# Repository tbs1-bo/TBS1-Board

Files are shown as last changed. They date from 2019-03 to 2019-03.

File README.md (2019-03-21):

# TBS1-Board

Das "TBS1-Board" ist ein Übungsboard zur Programmierung von Mikrocontrollern. Es wurde 2017 im Rahmen eines Projektes der Fachschule für Technik an der Technischen Beruflichen Schule 1 in Bochum (TBS1) entwickelt. Das Übungsboard kommt bei der Technikerausbildung zum Einsatz.

## TBS1-Board 2017

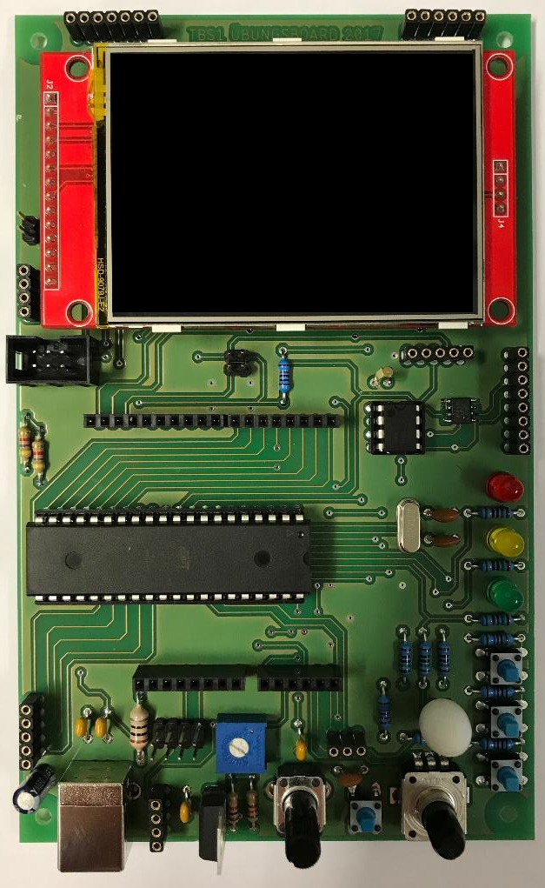
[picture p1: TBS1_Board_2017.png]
TBS1-Board 2017


- [Projektdokumentation (Auszug)](Projektdokumentation_2017_Auszug.pdf)
- [Schaltung und Platinenlayout](Schaltung_und_Platinenlayout)

## Weiterentwicklung

Infos folgen ...

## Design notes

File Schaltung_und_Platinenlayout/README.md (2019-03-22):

# TBS1-Board / Schaltung und Platinenlayout (Stand: 2017)

- [Stückliste](Stueckliste_2017.pdf)

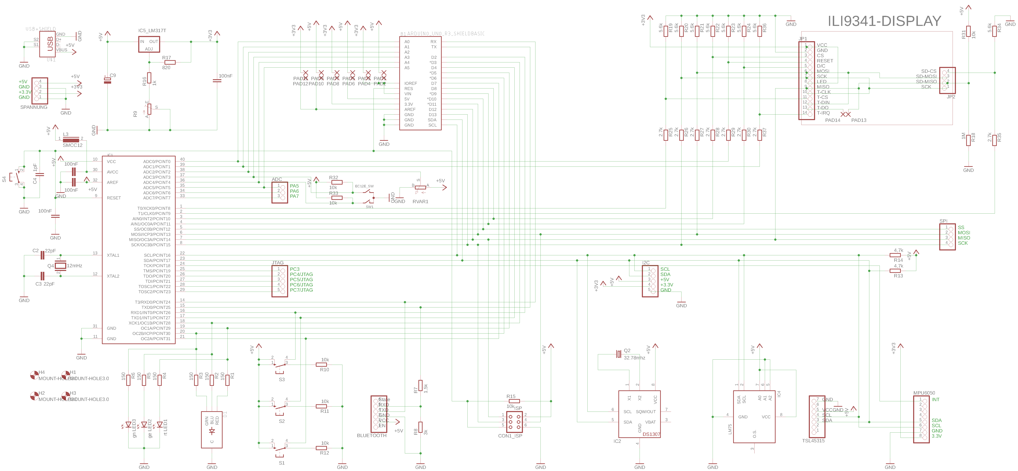
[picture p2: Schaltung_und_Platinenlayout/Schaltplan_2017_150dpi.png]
TBS1-Board Schaltplan

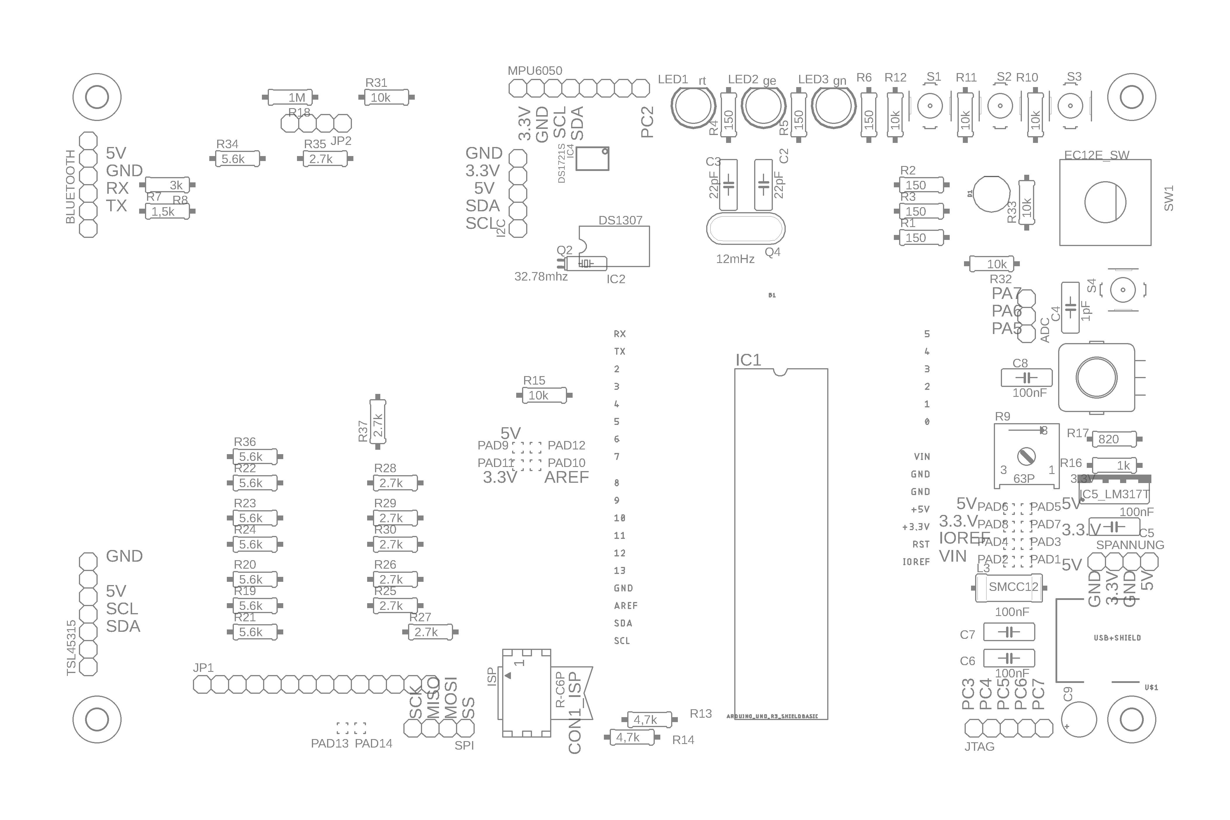
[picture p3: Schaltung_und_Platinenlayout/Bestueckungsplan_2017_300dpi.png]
TBS1-Board Bestückungsplan


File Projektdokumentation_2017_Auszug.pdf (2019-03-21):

Zusammenfassung | [9]

## 1 Zusammenfassung

Die Projektgruppe hat sich für das schulinterne Projekt „Re-Design des TBS1-Boards“ entschieden. Dieses bietet der Projektgruppe die Möglichkeit, sich in ein für alle Gruppenmitglieder neues Themengebiet einzuarbeiten. Die Motivation der Projektgruppe ist die individuelle Weiterentwicklung im Bereich der Mikrocontrollertechnik und das Lösen neuer Herausforderungen. Technische Herausforderung der Projektgruppe war die Einarbeitung in die Programmiersprache C und der Umgang mit dem AVR Studio. Ziel dieses Projektes ist die Planung und Entwicklung eines neuen Mikrocontroller-Übungsboards, das in Form einer Platine übergeben wird. Studierende des Fachbereiches „Elektrotechnik“ werden das Übungsboard in Lernfeld 9 an der TBS1 nutzen, um Kenntnisse der Mikrocontrollertechnik zu erlangen und zu vertiefen.

Basierend auf einem Übungsboard, das im Jahre 2011 gefertigt wurden, wurde das TBS1-Übungsboard nach neuen Anforderungen des Unterrichtskonzepts entwickelt. Diese enthalten die Ansteuerung von einer RGB-LED, eine Verwendung eines TFT Multi-Color-Displays, die Kommunikation über Bluetooth-Module und I²C-Busteilnehmern. Zu Beginn des Projekts wurde der Ist-Zustand des alten Übungsboards genau analysiert. So konnte geprüft werden, welche Komponenten auf das TBS1-Board übernommen werden konnten.

Aufgrund der komplexen und anspruchsvollen Änderungen, die vorgenommen mussten, wurde das Gesamtprojekt innerhalb der Gruppe in Teilprojekte aufgeschlüsselt. Nachdem
Recherche-, | Programmierungs- | und | Entwicklungsphase | der | Einzelprojekte
abgeschlossen waren, konnten die Projekte für die Realisierung des Übungsboards zusammengefügt werden. Dazu wurden Steckboardversuche durchgeführt, um das Zusammenspiel aller Komponenten des TBS1-Übungsboards zu testen und mögliche Fehler ausfindig zu machen. Nachdem keine Fehlerquellen mehr in der Hard- und Software ausfindig gemacht werden konnten, wurde mit der Herstellung des Platinenlayouts begonnen. Die maschinell hergestellte Prototypplatine konnte den weitreichenden Anwendungstests standhalten und so durch die TBS1 in Serienfertigung gegeben werden. Des Weiteren wurde eine Gesamtsimulation mit dem Programm „Proteus 8 Professional“ entwickelt, sodass die Funktion des Übungsboards auch an einem Computer voll simulierfähig genutzt werden kann. Am Ende des Projekts konnte dem Auftraggeber ein voll funktionsfähiges Mikrocontroller-Übungsboard mit Simulationsprogramm und vollständiger Dokumentation übergeben werden.

Abstract | [10]

## 2 Abstract

The project team decided to deal with the school internal topic "Re-Design of the TBS1-Board". Thus, all the members of the project team are given the opportunity to work on new thematics. The motivation of the project team consists of the individual development in the field of microcontroller technology as well as facing new challenges. Technical challenges the team had to face were the initial training concerning the programming language C and handling the AVR-Studio. The aim of this project is the design and the development of a new microcontroller practice board which will be handed over in form of a printed circuit board. The practice board will be used by students of the department of electrical engineering in the course of learning field 9 at the TBS1 in order to gain and to deepen their knowledge in microcontroller technology

Based on a practice board which was manufactured in 2011 the new TBS1 practice board was developed according to the new tasks of the tuitional concept. These include the activation of a RGB-LED, the usage of a TFT Multi-Color-Display, the communication via Bluetooth modules and I²C-Bus participants. At the beginning of the project the actual state of the old practice board was analysed in detail. Thus, it could be examined which components could be taken over on the new TBS1 board.

Due to complex and demanding modifications that had to be made the overall project was divided into several sub-projects among the participants. After finishing the different stages of research, programming and development of the single projects, these could be put together for the realisation of the practice board. For this purpose breadboard experiments were performed in order to test the interaction of all the components of the TBS1 practice board and to detect possible faults. As no more faults could be detected in hardware and software the production of the printed circuit board layout started. The machine-made prototype circuit board could stand the close examination and thus the batch fabrication could start. Moreover, an over-all simulation was developed with the programme "Proteus 8 Professional". Consequently the function of the practice board can also be simulated on a computer. At the end of the project the client received a fully operative microcontroller practice board including a simulation programme and a complete documentation.

Einleitung | [11]

## 3 Einleitung

Die Technische Berufliche Schule 1 in Bochum nutzt in Lernfeld 9 seit 2011 ein Übungsboard. Es ermöglicht Studierenden innerhalb ihrer Weiterbildung zum „Staatlich Geprüften Techniker in der Fachrichtung Elektrotechnik“, die Kenntnisse und Fertigkeiten in der Mikrokontrollertechnik praktisch zu erlernen und zu vertiefen. Da es sich um eine sehr komplexe und wichtige Fachkompetenz handelt, setzt der Rahmenplan der Landesregierung NRW im Lernfeld 9 120 bis 280 Unterrichtsstunden an. Das TBS1-Board wird dazu von jedem Studierenden selbst gefertigt. Durch die beiliegende Materialliste können alle benötigten Komponenten bestellt und die TBS1-Board-Platine durch die Studierenden bestückt und gelötet werden.

Das bis dato genutzte TBS1-Übungsboard erwies sich als nützliche Komponente, die theoretisch erlernten Kenntnisse der Mikrocontrollertechnik sofort an praktischer Hardware anwenden zu können. Grund für die Überarbeitung des TBS1-Boards war es, das Übungsboard wieder auf den aktuellsten Stand der Technik zu bringen und eine Serienfertigung für die nächsten Schuljahre zu ermöglichen.

Im Folgenden weitere Gründe für das Re-Design des TBS1-Boards:

- Bevorstehende Großbestellung neuer Platinen
- TFT Multicolor-Display zum gleichen Preis des bisherigen Zwei-Zeilen-Monochrom-Grafikdisplay erhältlich. Grafiken und Diagramme können so dargestellt werden.
- Neue Möglichkeiten ausschöpfen (Einbindung von Bluetooth-Modulen, Ansteuerung einer RGB-LED, weiterführende Nutzung von I²C-Sensorik)
- Kompatibilität mit Arduino-Komponenten ermöglichen

Projektteam | [12]

## 4 Projektteam

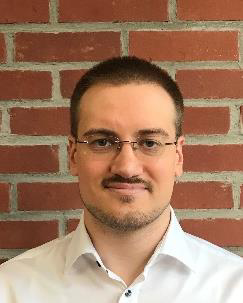
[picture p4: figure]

Name: | Martin Janocha
Geboren am: | 11.10.1989
Ausbildung: | Elektroniker für Energie- und Gebäudetechnik
Letzter Arbeitgeber: Walter Elektro Anlagentechnik GmbH
Aufgabenbereich: | Schaltschrankbau

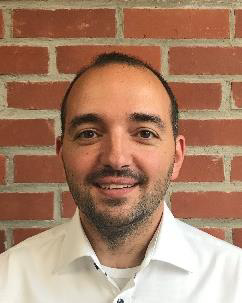
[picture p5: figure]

Name: | Christoph Nabring
Geboren am: | 19.04.1980
Ausbildung: | Elektroniker für Energie- und Gebäudetechnik
Letzter Arbeitgeber: United Cinemas International Multiplex GmbH
Aufgabenbereich: | Facility Management (GLT etc.)

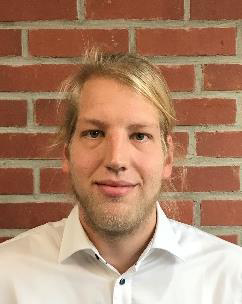
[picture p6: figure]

Name: | Dustin Rosemann
Geboren am: | 16.02.1992
Ausbildung: | Elektroniker für Betriebstechnik
Letzter Arbeitgeber: Vossloh Fastening Systems AG
Aufgabenbereich: | Internationales Projektmanagement

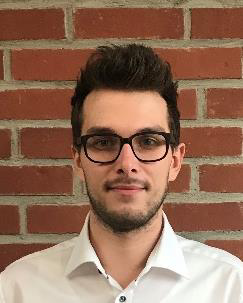
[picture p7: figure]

Name: | Nathanael Runge
Geboren am: | 19.06.1992
Ausbildung: | Mechatroniker
Letzter Arbeitgeber: Alanod GmbH Aufgabenbereich: SPS-Automatisierung

TBS1-Boards im Vergleich | [13]

## 5 TBS1-Boards im Vergleich

Um einen direkten Vergleich der TBS1-Boards zu erlangen, sind die TBS1-Boards in den folgenden zwei Abbildungen gegenübergestellt.

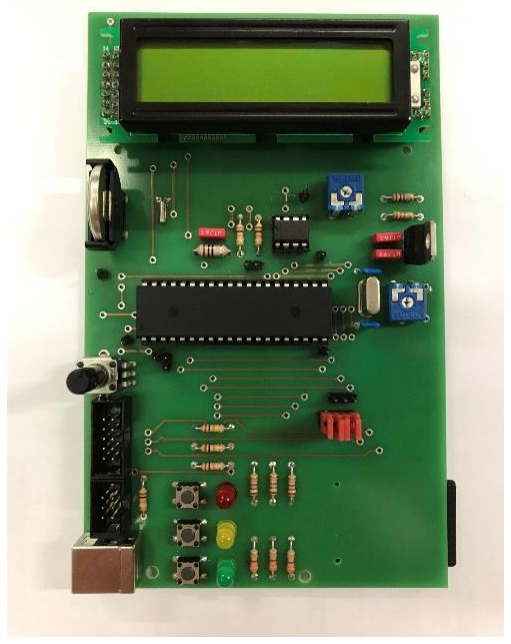
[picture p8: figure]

Die Auflistung der Hauptkomponenten des TBS1-Boards von 2011:

- Mikrocontroller ATmega 32
- Zwei-Zeilen-Monochrom-Display
- SD-Karten-Schnittstelle (ohne konstante Funktion)
- Temperaturbaustein DS-1621
- RealTimeClock DS-1338
- Drehpotentiometer
- LED-Ampel
- Drei Kurzhubtaster

Abb. 1: TBS1-Board 2011

TBS1-Boards im Vergleich | [14]

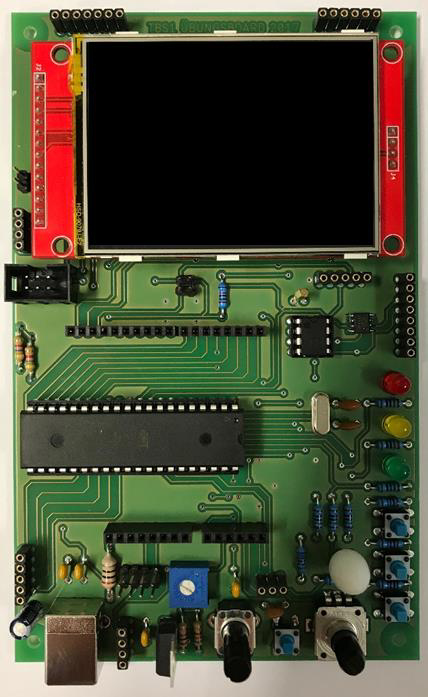
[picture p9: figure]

Abb. 2: TBS1-Board 2017
Die Auflistung der Hauptkomponenten des TBS1-Board von 2017:
- Mikrocontroller ATmega 1284P
- TFT Multicolor-Grafikdisplay
- SD-Karten-Schnittstelle
- Temperatursensor LM75A
- Drehimpulsgeber
- Drehpotentiometer
- RealTimeClock DS-1338
- LED-Ampel
- Drei Kurzhubtaster
- RGB-LED
- Resetbutton
- Steckleiste für Arduino-Shields
- Steckleiste für Lichtsensor TSL45315
- Steckleiste für Gyrosensor MPU-6050
- Steckleiste für Bluetooth-Module (IOS und Android)
- Breakout für SPI
- Breakout für I²C

TBS1-Boards im Vergleich | [15]
- Breakout für JTAG
- Breakout für ADC-Eingänge
- Breakout für Interrupteingänge
- Breakout der Spannungsversorgung (3,3V; 5V; Masse)

Bei der Entwicklung des TBS1-Boards wurde auf eine bedienerfreundliche und kompakte Bauform geachtet. An den Steckleisten am Rand des TBS1-Boards können Sensoren bei Bedarf hinzugefügt oder entfernt werden. Um das Übungsboard durch weitere, nicht eingeplante Komponenten oder Sensoren zu erweitern, können die verschiedenen Breakouts genutzt werden. Es ermöglicht u. A. das Einbinden weiterer Sensoren in den I²C-Bus, die Erweiterung von SPI-Komponenten oder die Nutzung von nicht belegten Hardwarepins am ATmega1284P. Für weitergehende Programmierungsmöglichkeiten kann natürlich auch das Arduino-Shield-Breakout genutzt werden.

Der Mikrocontroller ATmega1284P | [16]

## 6 Der Mikrocontroller ATmega1284P

Der Mikrocontroller, auch Halbleiterchip bzw. „Ein-Chip-Mikrorechner“, ist ein Rechensystem, welches eine ähnliche Funktionsweise wie ein Computer hat. Im Gegensatz zu einem PC sind die Eigenschaften, der Programmspeicher (Flash), der Datenspeicher (RAM), die Verarbeitungseinheit (CPU), die digitalen und analogen Ein-/Ausgabe-Ports, Kommunikationsbausteine (COM, UART, etc.), Zeitgeber usw., alle auf dem Mikrocontroller vereint. Durch diese Minimalisierung und die individuelle Anwendungsanpassung können die Produktionskosten drastisch gesenkt werden. Dementsprechend gibt es viele unterschiedliche Varianten, welche sich in der Bauform und dem Funktionsumfang unterscheiden. Der Mikrocontroller übernimmt, je nach Programmierung, bei seiner Anwendung meistens Überwachungs-, Steuer- oder Regelaufgaben. So kommen Mikrocontroller in immer mehr elektrischen Geräten des alltäglichen Lebens zum Einsatz, wie z.B. Fernsehern, Waschmaschinen, Mobiltelefonen, Steuergeräten von Kraftfahrzeugen, Uhren und Heizungsreglern. Mikrocontroller können mit verschiedenen Programmiersprachen programmiert werden. Zu den gängigsten Programmiersprachen zählen z.B. Assembler, Basic, Arduino-C, C++ oder C.

Für dieses Projekt wird der ATmega1284P ausgewählt, da er im Vergleich zum zuvor benutzten ATmega32 einen vier Mal größeren internen Flash-Speicher und EEPROM sowie einen acht Mal größeren SRAM besitzt. Dadurch können z.B. größere Libraries, wie die des Displays, gespeichert und verarbeitet werden. Beide Mikrocontroller sind hinsichtlich der Abmaße baugleich und benötigen beide einen 40-Pin-Sockel.

Der ATmega1284P gehört zur 8-Bit-Mikrocontroller-Familie des US-amerikanischen Herstellers Microchip Technology´s. Eine genauere Beschreibung der Funktionen ist dem Datenblatt zu entnehmen.

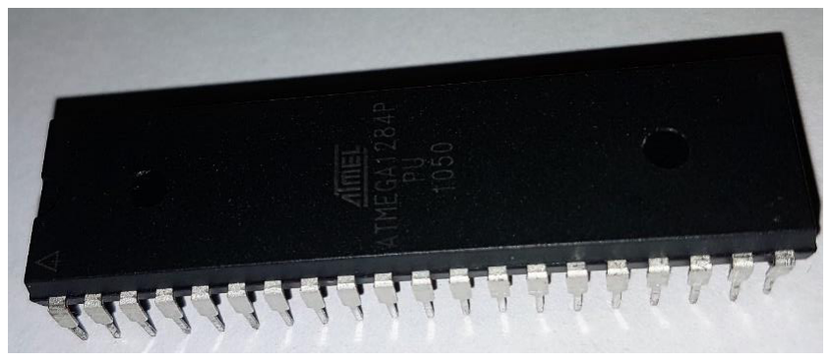
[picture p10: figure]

Abb. 3: ATmega 1284p (DIL40)

Der Mikrocontroller ATmega1284P | [17]

Im Rahmen des Projektes werden folgende Funktionen zur Umsetzung verwendet:

- SPI-Schnittstelle (Serial Peripheral Interface)
Diese Schnittstelle ist ein Bussystem, über welches mehrere Komponenten gleichzeitig kommunizieren können. Bei dem Projekt dient sie zur Kommunikation zwischen dem Display, der SD-Karte und dem ATmega1284P.
- ISP-Schnittstelle (In System Programming)
Diese Schnittstelle teilt sich die Pins der SPI-Schnittstelle und wird von Programmiergeräten benutzt, um das fertige Programm auf den Mikrocontroller zu übertragen.
- I²C-Bus (I-Quadrat-C = Interner IC Bus)
Diese Zweidraht-Schnittstelle ist ein Bussystem, über welches mehrere I²C-Bausteine mit dem Mikrocontroller kommunizieren können.

Fuse-Bits Einstellungen Mikrocontroller | [18]

## 7 Fuse-Bits Einstellungen Mikrocontroller

Fuse-Bits dienen dazu, Einstellungen des Mikrocontrollers zu ändern, die nicht im Programm verändert werden können. Unter anderem wird damit die Nutzung des internen Takts eingestellt oder die Verwendung eines externen Quarzes. Der Mikrocontroller des Boards muss so eingestellt werden, dass der externe Takt verwendet wird.

Zur Einstellung der Fuse-Bits werden folgende Register (Bytes) verwendet:
Low-, High- und Extended-Fuse.

Die Fuse-Bits des ATmega1284P vom TBS1-Bord werden wie folgt eingestellt:
Low: 0xFF | High: 0x99 | Extended: 0xFF

Dadurch ist der Mikrocontroller so eingestellt, dass der interne Takt nicht durch 8 geteilt und ein externer Quarz akzeptiert wird.

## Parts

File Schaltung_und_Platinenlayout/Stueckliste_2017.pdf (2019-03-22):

TBS1-Board 2017 Stückliste

Stückliste (Stand: 22.03.2019)

Produkt (Reichelt) | Artikelnummer | EP (Euro)Menge GP (Euro)
Atmega 1284P | ATMEGA 1284P-PU | 4,7 | 1 | 4,7
IC Sockel 40 | GS 40 | 0,13 | 1 | 0,13
Drehpot. 10k Ohm | RK09K113-LIN10K | 0,76 | 1 | 0,76
Drehimpulsgeber | STEC12E07 | 1,7 | 1 | 1,7
Kurzhubtaster | TASTER 9308 | 0,16 | 4 | 0,64
LED ROT | LED 5MM ST RT | 0,12 | 1 | 0,12
LED GELB | LED 5MM ST GE | 0,12 | 1 | 0,12
LED GRÜN | LED 5MM ST GN | 0,12 | 1 | 0,12
RGB-LED Kathode | LED LL 5-8000RGB | 0,61 | 1 | 0,61
USB Buchse | USB BW | 0,26 | 1 | 0,26
Wannenstecker 6-polig | WSL 6G | 0,16 | 1 | 0,16
RTC Sockel SO-8 | GS 8 | 0,04 | 1 | 0,04
Quarz 12 MHz | 12,0000-HC49U-S | 0,21 | 1 | 0,21
Quarz 32,768 kHz | 32,768 MS1V-12,5 | 0,39 | 1 | 0,39
Jumper | JUMPER 2,54GL SW | 0,02 | 3 | 0,06
Jumper klein | JUMPER 2,54 SW | 0,01 | 1 | 0,01
Festspannungsregler | LM 317-220 SG | 0,22 | 1 | 0,22
Trimmpotentiometer | 76-10 1,0K | 0,3 | 1 | 0,3
Drosselspule 10u | SMCC 10μ | 0,22 | 1 | 0,22
Kondensator 1pF | KERKO-500 1,0P | 0,07 | 1 | 0,07
Kondensator 22pF | KERKO-500 22P | 0,07 | 2 | 0,14
Kondensator 100nF | KERKO 100N | 0,05 | 4 | 0,2
Kondensator 4,7uF | RAD 4,7/35 | 0,02 | 1 | 0,02
Stiftleiste 2Pin | MPE 087-1-002 | 0,05 | 1 | 0,05
Stiftleiste 4Pin | MPE 087-1-004 | 0,1 | 1 | 0,1
Stiftleiste 2x2Pin | MPE 087-2-004 | 0,09 | 1 | 0,09
Stiftleiste 2x4Pin | MPE 087-2-008 | 0,19 | 1 | 0,19
Buchsenleiste 3Pin | MPE 115-1-003 | 0,27 | 1 | 0,27
Buchsenleiste 4Pin | MPE 115-1-004 | 0,21 | 3 | 0,63
Buchsenleiste 5Pin | 1X05G7 2,54 | 0,26 | 2 | 0,52
Buchsenleiste 6Pin | BL 1X06G7 2,54 | 0,31 | 1 | 0,31
Buchsenleiste 7pin | MPE 115-1-007 | 0,4 | 1 | 0,4
Buchsenleiste 8 Pin | MPE 115-1-008 | 0,43 | 1 | 0,43
Buchsenleiste 14Pin | MPE 115-1-014 | 0,77 | 1 | 0,77
Buchsenleiste 8Pin 8,5mm | MPE 094-1-008 | 0,23 | 2 | 0,46
Buchsenleiste 6Pin 8,5mm | MPE 094-1-006 | 0,21 | 1 | 0,21
Buchsenleiste 10Pin 8,5mm | MPE 094-1-010 | 0,21 | 1 | 0,21
Temperatursensor LM75A | LM75AD | Bei Reichelt nicht verfügbar | Aus China sehr günstig
Temperatursensor (alternative)LM 75 SMD | 1,6 | 1 | 1,6
Real Time Clock | DS 1307 | 2,8 | 1 | 2,8 Aus China sehr günstig
Widerstand 150 Ohm | METALL 150 | 0,082 | 6 | 0,492
Widerstand 820 Ohm | 1/4W 820 | 0,103 | 1 | 0,103
Widerstand 1k Ohm | 1/4W 1,0K | 0,103 | 1 | 0,103
Widerstand 1,5K Ohm | 1/4W 1,5K | 0,103 | 1 | 0,103
Widerstand 2,7k Ohm | 1/4W 2,7K | 0,103 | 8 | 0,824
Widerstand 3,0K Ohm | 1/4W 3,0K | 0,103 | 1 | 0,103
Widerstand 4,7K Ohm | 1/4W 4,7K | 0,103 | 2 | 0,206
Widerstand 5,6k Ohm | 1/4W 5,6K | 0,103 | 8 | 0,824
Widerstand 10K Ohm | METALL 10,0K | 0,082 | 7 | 0,574
Widerstand 1M Ohm | 1/4W 1M | 0,103 | 1 | 0,103
23,675

Sonstiges
Platinen Herstellung | 160mm x 100mm
Display | 2.8" TFT LCD Display Touch Panel SPI Serial 240*320 ILI9341 5V/3.3V STM32
| | 6,62 € (https://www.ebay.de/itm/2-8-TFT-LCD-Display-Touch-Panel-SPI-Serial-240-320-ILI9341-5V-3-3V-STM32/382397394621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)

Optional
ACHTUNG: Das Bluetooth-Modul ist nicht mit allen Smartphones kompatibel
Lichtsensor | TSL45315 | Watterott | 7,50 €
Bluetooth-Modul | HC-05 X | Amazon

https://www.ebay.de/itm/2-8-TFT-LCD-Display-Touch-Panel-SPI-Serial-240-320-ILI9341-5V-3-3V-STM32/382397394621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

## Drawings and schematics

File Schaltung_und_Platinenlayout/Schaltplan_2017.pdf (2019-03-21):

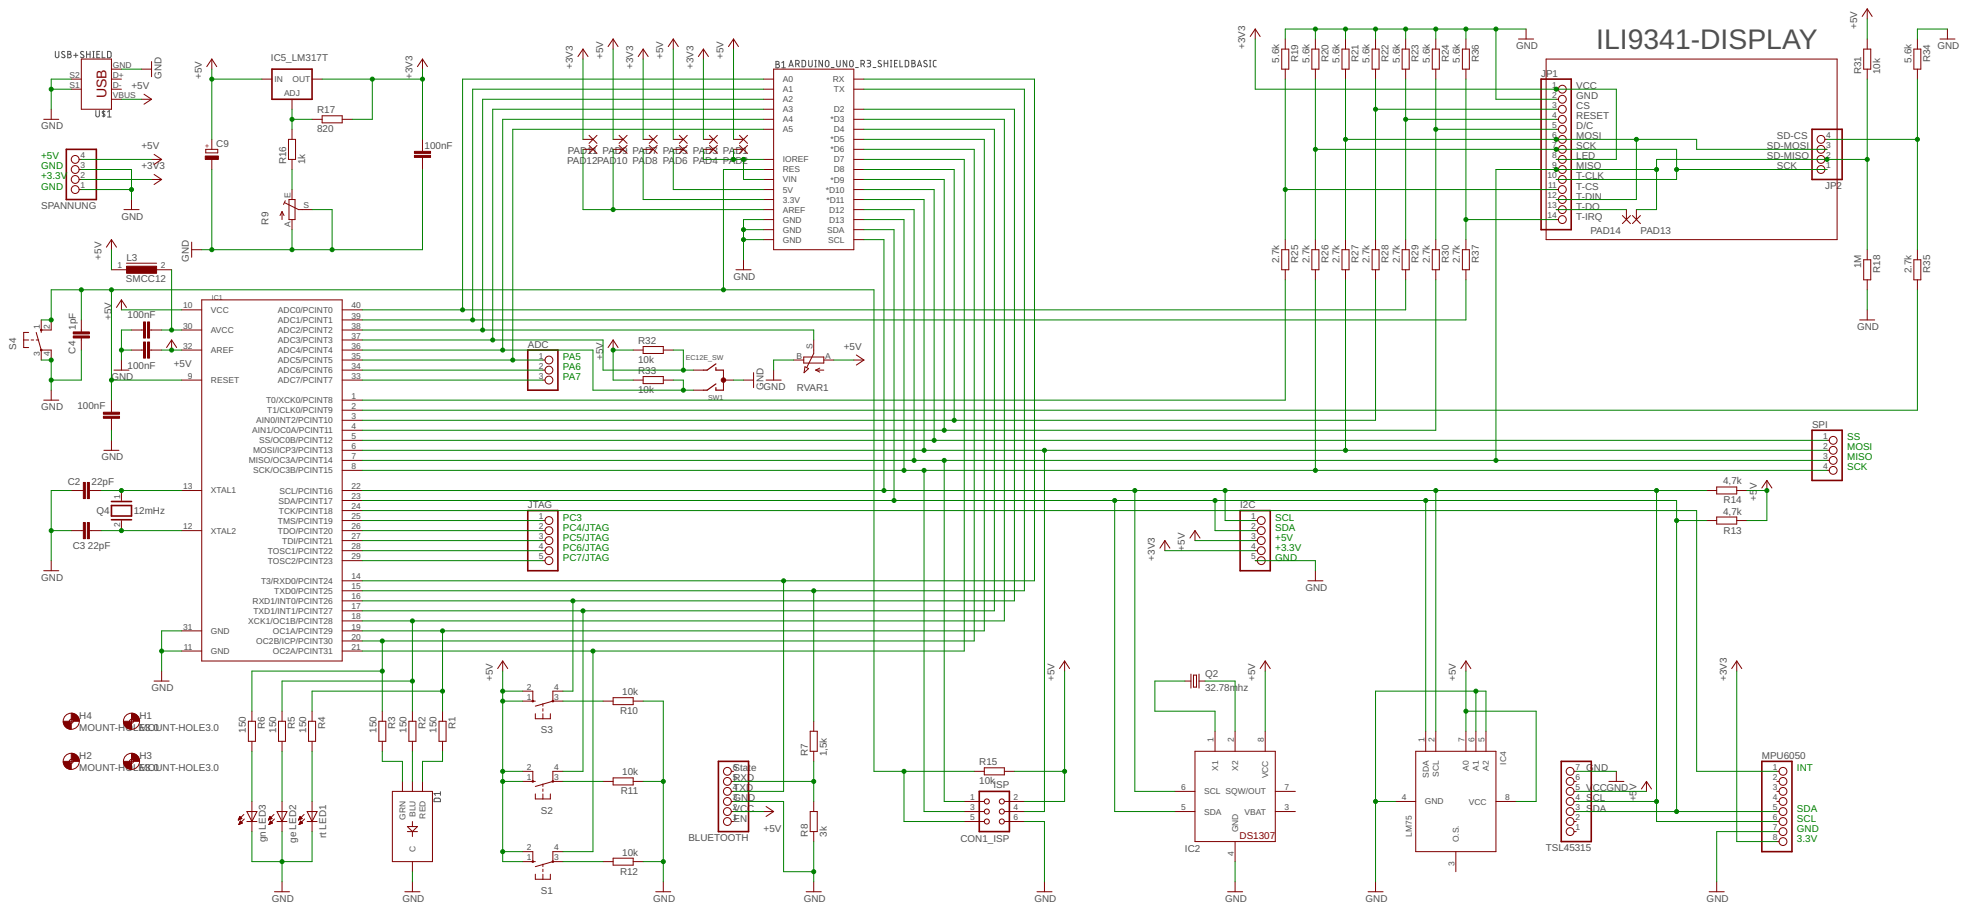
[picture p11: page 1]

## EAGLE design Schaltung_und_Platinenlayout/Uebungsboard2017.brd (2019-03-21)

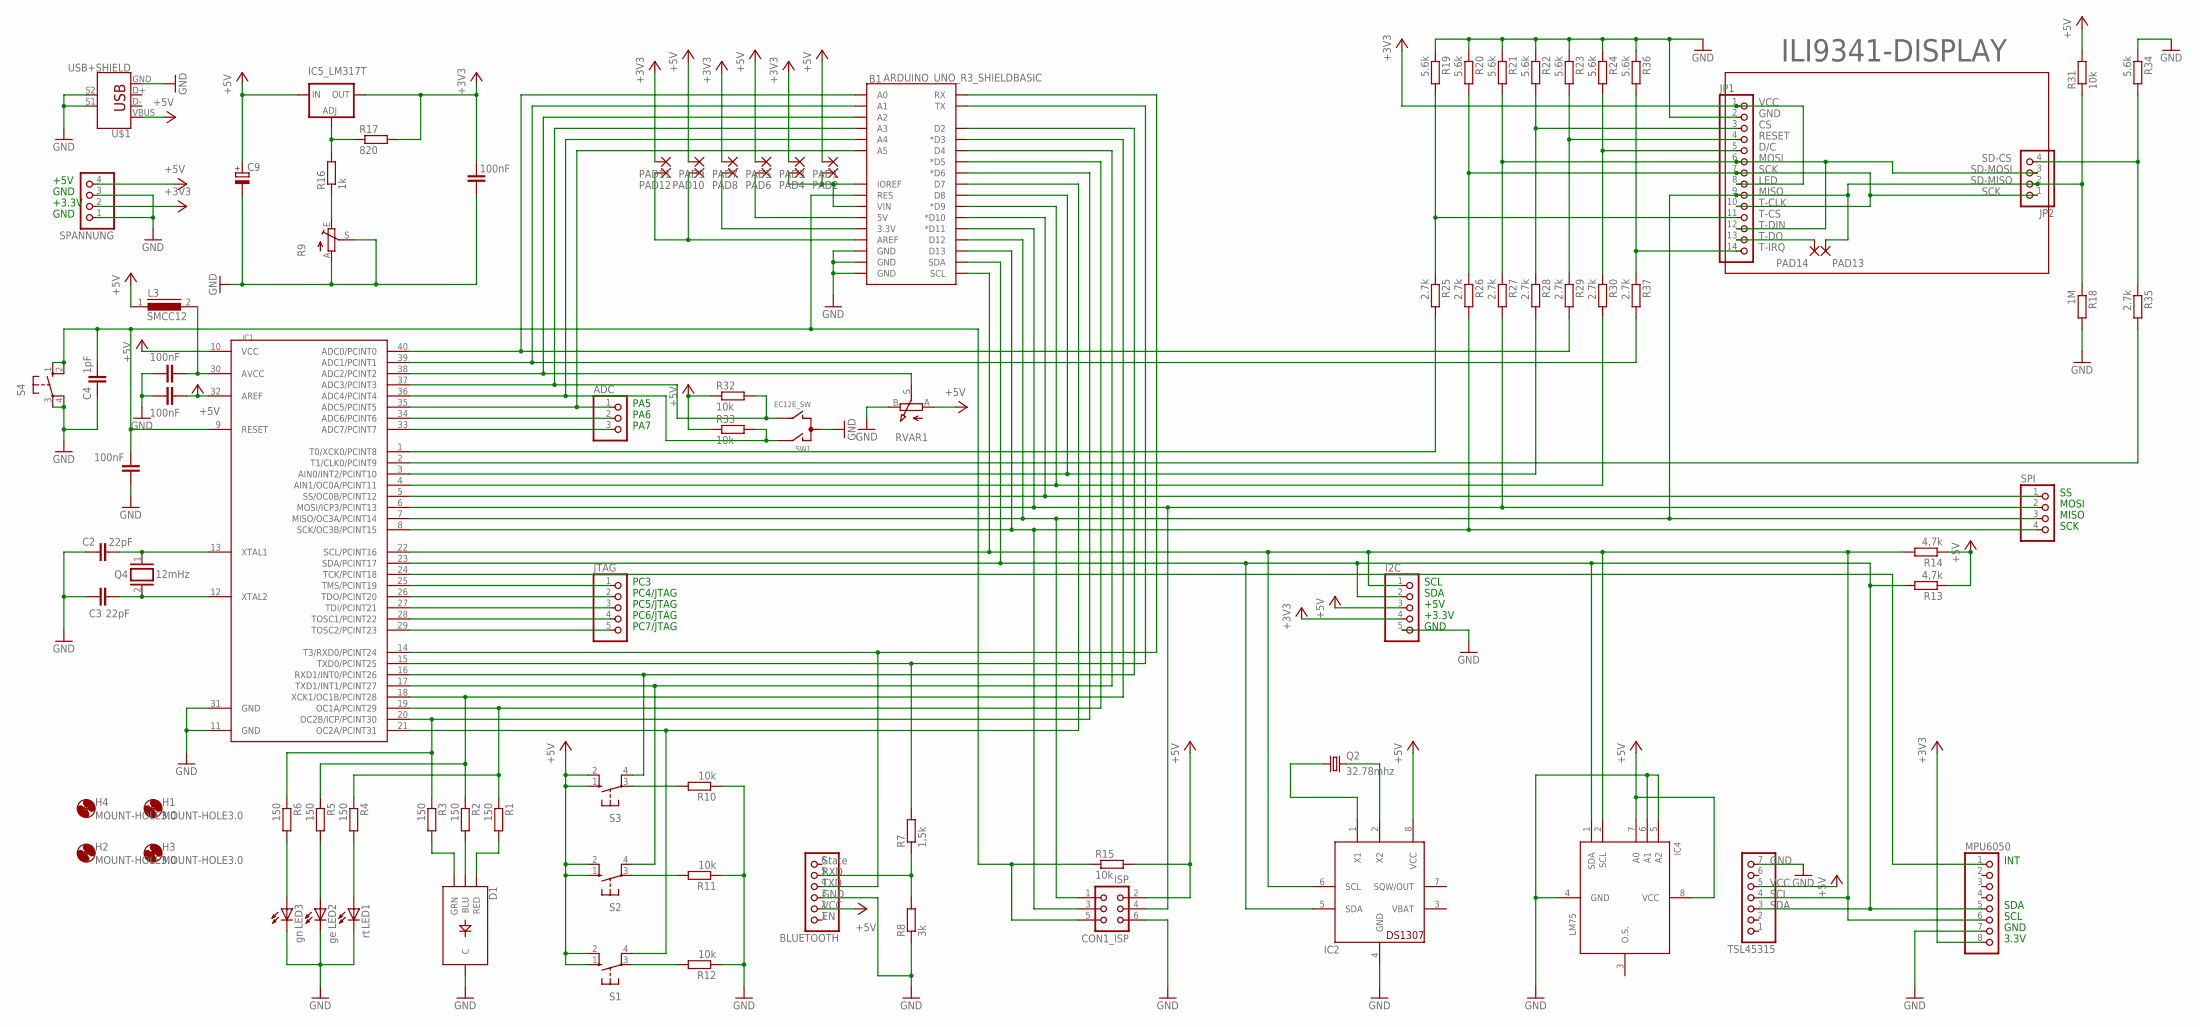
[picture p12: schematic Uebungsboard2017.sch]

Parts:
ADC: PINHD-1X3; 1X03
B1: ARDUINO_UNO_R3_SHIELDBASIC; UNO_R3_SHIELD
BLUETOOTH: PINHD-1X6; 1X06
C2, C3: 22pF; C5B2.5
C4: 1pF; C5B2.5
C5, C6, C7, C8: 100nF; C5B2.5
C9: CPOL-EUE2-5; E2-5
CON1_ISP: ISP; CON06
D1: LED-RGB-CCTEST; LED-RGB-THRU
H1, H2, H3, H4: MOUNT-HOLE3.0; 3,0
I2C: PINHD-1X5; 1X05
IC1: MEGA1284P; DIL40
IC2: DS1307; DIL08
IC4: DS1721S; SO-8
IC5_LM317T: 3.3V; 317TS
JP1: PINHD-1X14; 1X14
JP2: PINHD-1X4; 1X04
JTAG: PINHD-1X5; 1X05
L3: SMCC12
LED1: rt; LED5MM
LED2: ge; LED5MM
LED3: gn; LED5MM
MPU6050: PINHD-1X8; 1X08
PAD1, PAD2, PAD3, PAD4, PAD5, PAD6, PAD7, PAD8, PAD9, PAD10, PAD11, PAD12, PAD13, PAD14: 1,6/0,8
Q2: 32.78mhz; TC26H
Q4: 12mHz; QS
R1, R2, R3, R4, R5, R6: 150; 0207/10
R7: 1,5k; 0207/10
R8: 3k; 0207/10
R9: TRIM_EU-S63P; S63P
R10, R11, R12, R15, R31, R32, R33: 10k; 0207/10
R13, R14: 4,7k; 0207/10
R16: 1k; 0207/10
R17: 820; 0207/10
R18: 1M; 0207/10
R19, R20, R21, R22, R23, R24, R34, R36: 5.6k; 0207/10
R25, R26, R27, R28, R29, R30, R35, R37: 2.7k; 0207/10
RVAR1: RK09K113
S1, S2, S3, S4: 10-XX; B3F-10XX
SPANNUNG: PINHD-1X4; 1X04
SPI: PINHD-1X4; 1X04
SW1: EC12E_SW; ALPS_EC12E_SW
TSL45315: PINHD-1X7; 1X07
U$1: USB+SHIELD; USB-B-PTH

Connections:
+3V3: C5.1, I2C.4, IC5_LM317T.2 (OUT), JP1.1, JP1.8, MPU6050.8, PAD3.1, PAD7.1, PAD11.1, R17.2, SPANNUNG.2
+5V: BLUETOOTH.2, C6.1, C9.+, CON1_ISP.2, I2C.3, IC1.10 (VCC), IC1.32 (AREF), IC2.8 (VCC), IC4.7 (A0), IC4.8 (VCC), IC5_LM317T.3 (IN), L3.1, PAD1.1, PAD5.1, PAD9.1, R13.1, R14.1, R15.2, R31.2, R32.1, R33.1, RVAR1.A, S1.1 (S), S1.2 (S1), S2.1 (S), S2.2 (S1), S3.1 (S), S3.2 (S1), SPANNUNG.4, TSL45315.5, U$1.VBUS
GND: B1.GND@0 (GND), B1.GND@1 (GND), B1.GND@2 (GND), BLUETOOTH.3, C2.2, C3.1, C4.2, C5.2, C6.2, C7.2, C8.2, C9.-, CON1_ISP.6, D1.2 (C), I2C.5, IC1.11 (GND), IC1.31 (GND), IC2.4 (GND), IC4.4 (GND), IC4.5 (A2), IC4.6 (A1), JP1.2, LED1.K (C), LED2.K (C), LED3.K (C), MPU6050.7, R8.1, R9.A, R9.S, R10.1, R11.1, R12.1, R18.2, R19.1, R20.1, R21.1, R22.1, R23.1, R24.1, R34.1, R36.1, RVAR1.B (E), S4.3, S4.4 (P1), SPANNUNG.1, SPANNUNG.3, SW1.C, TSL45315.7, U$1.GND, U$1.S1, U$1.S2
unnamed: B1.D5 (*D5), IC1.19 (OC1A/PCINT29), R1.1, R4.1
unnamed: C2.1, IC1.13 (XTAL1), Q4.1
unnamed: B1.D3 (*D3), IC1.18 (XCK1/OC1B/PCINT28), R2.1, R5.1
unnamed: C3.2, IC1.12 (XTAL2), Q4.2
unnamed: B1.D6 (*D6), IC1.20 (OC2B/ICP/PCINT30), R3.1, R6.1
unnamed: D1.1 (RED), R1.2
unnamed: D1.4 (BLU), R2.2
unnamed: D1.3 (GRN), R3.2
unnamed: LED1.A, R4.2
unnamed: LED2.A, R5.2
unnamed: LED3.A, R6.2
unnamed: B1.D12, CON1_ISP.1, IC1.7 (MISO/OC3A/PCINT14), JP1.9, JP2.2, PAD13.1, R18.1, R31.1, SPI.3
unnamed: ADC.1, B1.A5, IC1.35 (ADC5/PCINT5)
unnamed: IC2.2 (X2), Q2.2
unnamed: B1.D11 (*D11), CON1_ISP.4, IC1.6 (MOSI/ICP3/PCINT13), R27.2, SPI.2
unnamed: B1.A1, IC1.39 (ADC1/PCINT1), R37.2
unnamed: IC1.24 (TCK/PCINT18), MPU6050.1
unnamed: B1.A2, IC1.38 (ADC2/PCINT2), RVAR1.S
unnamed: IC5_LM317T.1 (ADJ), R16.2, R17.1
unnamed: IC2.1 (X1), Q2.1
unnamed: B1.RX, BLUETOOTH.4, IC1.14 (T3/RXD0/PCINT24)
unnamed: BLUETOOTH.5, R7.1, R8.2
unnamed: B1.SCL, I2C.1, IC1.22 (SCL/PCINT16), IC2.6 (SCL), IC4.2 (SCL), MPU6050.6, R14.2, TSL45315.4
unnamed: B1.D4, IC1.17 (TXD1/INT1/PCINT27), S2.4 (P1)
unnamed: B1.D2, IC1.16 (RXD1/INT0/PCINT26), S3.4 (P1)
unnamed: R10.2, S3.3
unnamed: R11.2, S2.3
unnamed: R12.2, S1.3
unnamed: C7.1, IC1.30 (AVCC), L3.2
unnamed: B1.TX, IC1.15 (TXD0/PCINT25), R7.2
unnamed: JP1.11, R19.2, R25.1
unnamed: IC1.25 (TMS/PCINT19), JTAG.1
unnamed: R9.E, R16.1
unnamed: JP1.7, JP1.10, JP2.1, R20.2, R26.1
unnamed: JP1.6, JP1.12, JP2.3, R21.2, R27.1
unnamed: JP1.3, R22.2, R28.1
unnamed: JP1.4, R23.2, R29.1
unnamed: JP1.5, R24.2, R30.1
unnamed: B1.A4, IC1.36 (ADC4/PCINT4), R33.2, SW1.A
unnamed: IC1.1 (T0/XCK0/PCINT8), R25.2
unnamed: B1.D8, IC1.3 (AIN0/INT2/PCINT10), R28.2
unnamed: B1.A0, IC1.40 (ADC0/PCINT0), R29.2
unnamed: B1.D9 (*D9), IC1.4 (AIN1/OC0A/PCINT11), R30.2
unnamed: B1.A3, IC1.37 (ADC3/PCINT3), R32.2, SW1.B
unnamed: JP2.4, R34.2, R35.1
unnamed: IC1.2 (T1/CLK0/PCINT9), R35.2
unnamed: IC1.26 (TDO/PCINT20), JTAG.2
unnamed: IC1.27 (TDI/PCINT21), JTAG.3
unnamed: IC1.28 (TOSC1/PCINT22), JTAG.4
unnamed: B1.D13, CON1_ISP.3, IC1.8 (SCK/OC3B/PCINT15), R26.2, SPI.4
unnamed: B1.D10 (*D10), IC1.5 (SS/OC0B/PCINT12), SPI.1
unnamed: B1.D7, IC1.21 (OC2A/PCINT31), S1.4 (P1)
unnamed: IC1.29 (TOSC2/PCINT23), JTAG.5
unnamed: B1.IOREF, B1.VIN, PAD2.1, PAD4.1
unnamed: B1.5V, PAD6.1
unnamed: B1.3.3V, PAD8.1
unnamed: B1.AREF, PAD10.1, PAD12.1
unnamed: ADC.2, IC1.34 (ADC6/PCINT6)
unnamed: ADC.3, IC1.33 (ADC7/PCINT7)
unnamed: JP1.13, PAD14.1
unnamed: B1.RES, C4.1, C8.1, CON1_ISP.5, IC1.9 (RESET), R15.1, S4.1 (S), S4.2 (S1)
unnamed: JP1.14, R36.2, R37.1
unnamed: B1.SDA, I2C.2, IC1.23 (SDA/PCINT17), IC2.5 (SDA), IC4.1 (SDA), MPU6050.5, R13.2, TSL45315.3
VBAT: IC2.3 (VBAT)

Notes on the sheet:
State
RXD
TXD
GND
VCC
SDA
SCL
ILI9341-DISPLAY
RESET
D/C
MOSI
SCK
LED
MISO
T-CLK
T-CS
T-DIN
T-DO
T-IRQ
SD-CS
SD-MOSI
SD-MISO
+5V
+3.3V
PA5
PA6
PA7
PC7/JTAG
PC6/JTAG
PC5/JTAG
PC4/JTAG
PC3
INT
3.3V

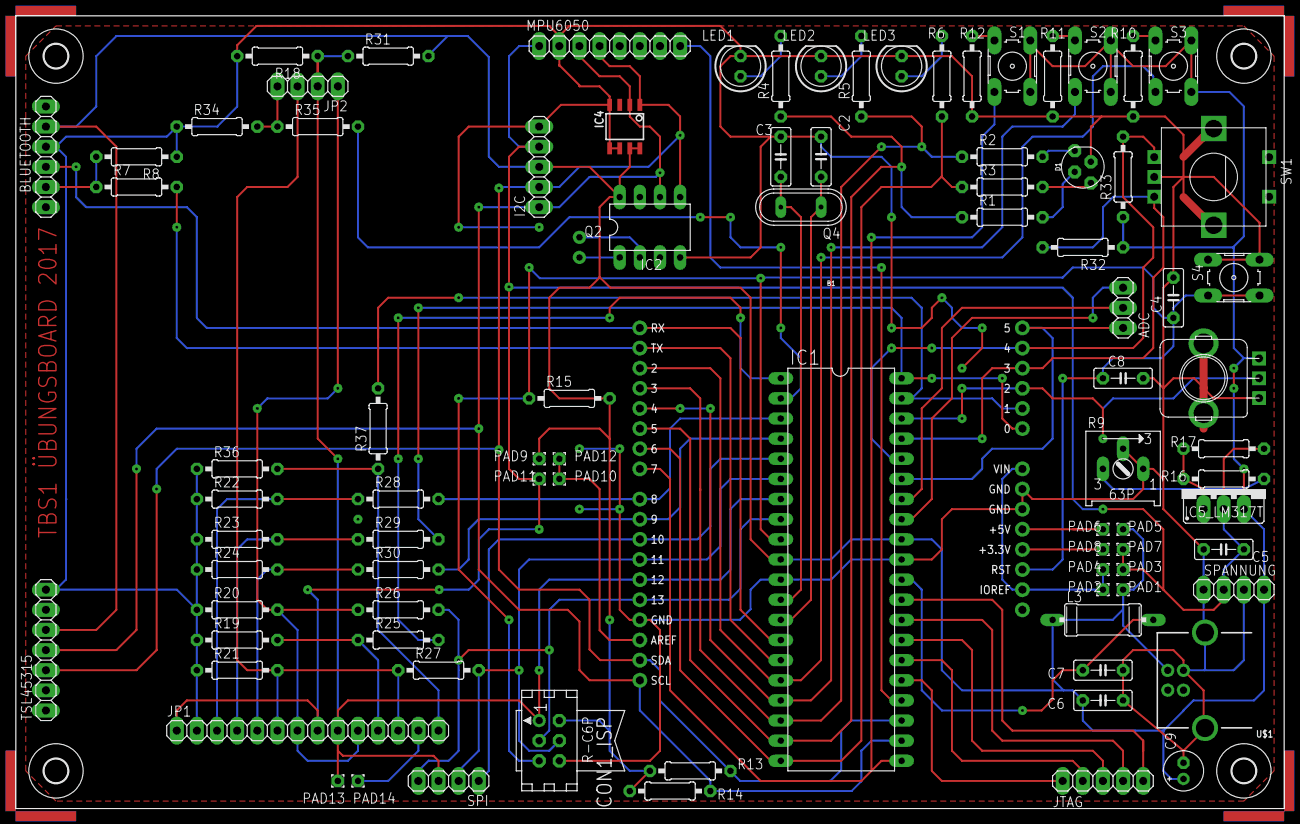
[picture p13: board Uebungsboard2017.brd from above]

Board: 2 copper layers, 160.0 x 100.0 mm, 101 parts (1 on the bottom side), 66 nets.

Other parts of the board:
U$2, U$3, U$4, U$5: ANGLE-ARROW-NW1
U$6, U$7, U$8, U$9: ANGLE-ARROW-NW1-16

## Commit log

2019-03-21 Schaltung und Layout (TBS1-Board 2017) hinzugefügt
    [Uebungsboard2017.brd, Uebungsboard2017.sch]
2019-03-21 keine Leerzeichen
    [Uebungsboard2017.brd, Uebungsboard2017.sch]

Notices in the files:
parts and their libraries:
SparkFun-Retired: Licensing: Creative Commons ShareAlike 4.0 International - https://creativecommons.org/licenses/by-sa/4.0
